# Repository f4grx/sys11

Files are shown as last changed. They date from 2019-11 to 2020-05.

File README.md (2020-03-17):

sys11
=====

This is a development board for the 68hc11 microcontroller.

The goal is to build a robust, simple, reliable, and repairable computer from
scrap, similar to what collapseOS is seeking.

The project defines two ROM images:
* a shell interface with assemble-time modular commands, development is halted.
* a forth interpreter.

Forth is a portable stack supported language wich is surprisingly powerful, even on
small targets. It has the potential to describe complex programs in a very compact way.

A lot of resources about forth are available online. This project defines a minimally small
forth interpreter with indirect threading. The goal is to build a 68hc11 interpreter that can
be used to write the interpreter itself, so it has to be as small as possible.

CPU: 68HC11A0, the most basic one. This is what I found in my drawer, and is
more desirable than a basic 6502 or other because it has integrated peripherals.
I only choose chips that I have replacement for.

Clock speed: 8 MHz XTAL / OSC, which translates to 2 MHz internal and
bus clock (Cycle time 500 ns). It seems that 16 MHz (4 MHz E clock, 250 ns
cycle) is also working. May switch to that later.

Currently sys11 is implemented on a protoboard using soldered 30AWG (wirewrap)
wires.

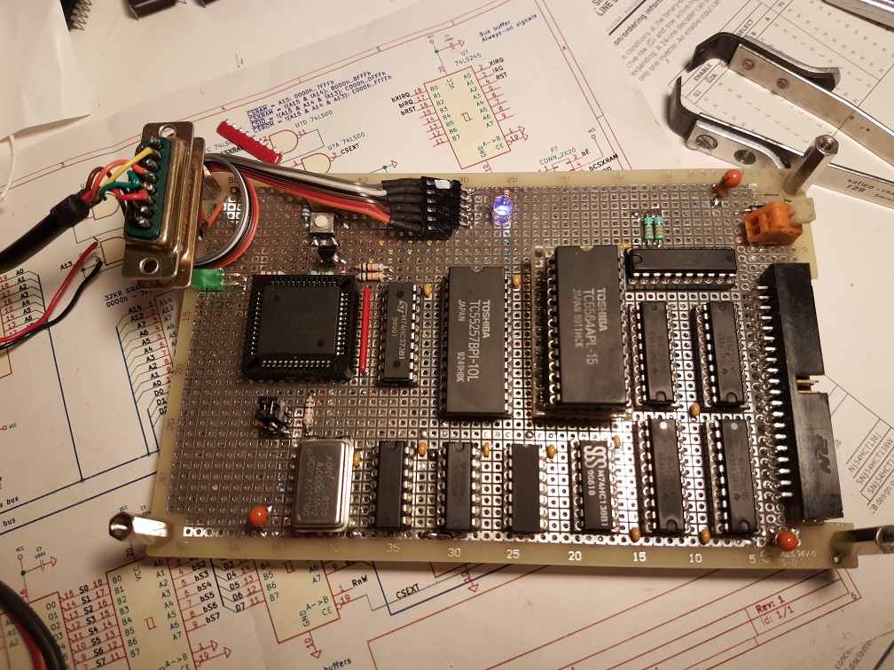
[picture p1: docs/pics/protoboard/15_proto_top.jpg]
Prototype top side


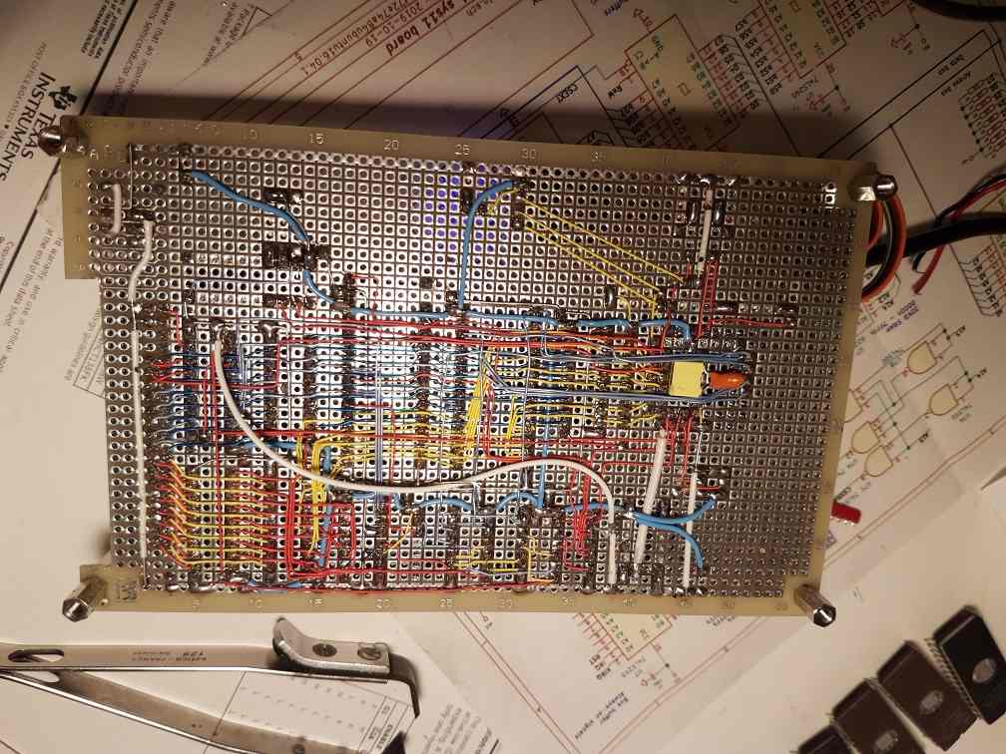
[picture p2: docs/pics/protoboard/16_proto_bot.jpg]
Prototype bottom side


Memory map (HC11 extended mode)
-------------------------------

* Internal RAM kept mapped at 0x0000
* Memory Mapped Registers mapped at 0x0000 (unusual). They overlay the internal
RAM, which means internal RAM locations 00h..3Fh are not usable (except the
locations that are reserved or related to PORTB and PORTC: 0002h-0007h).

* 32KB On-board Main SRAM (62256) in 0000h - 7FFFh CSRAM = A15
* 16KB Off-board secondary SRAM (half 62256) in 8000h - BFFFh, possibly banked
for additional space using a IO register. Then we could use an even bigger RAM
chip. CSXRAM = !(A15 & !A14)
* 8KB I/O space with 8 CS lines in C000h - DFFFh (1KB per CS)
CSIO = !(A15 & A14 & !A13)
* 8KB EPROM in E000h - FFFFh - monitor and SPI flash loader. For development,
this chip can be replaced with a RAM/EEPROM/NVRAM, the board actually use a
DIL32 socket instead of 28, that exposes the nWR line. An additional pair of DIL
sockets can be used to route this signal to the actual /WR line of the debug
RAM. This is actually using a 27256 EPROM with 4 manually selected banks, to
allow for different boot images (asm, communications, shell, storage mgmt, TBD)
CSROM = !(A15 & A14 & A13)
* External bus lines are only driven when external bus is actually addressed.
It is not driven when the on-board memory (32K RAM, 8K ROM) is addressed.
CSEXT = CSIO & CSXRAM

Main address decoding can be done with a few NAND gates (7400 2-input, and 7410
3-input NAND gates).

Peripherals
-----------

* 5V power from USB
* SCI : (UART), TX and RX lines on a pin header for external communication.
10K pullups are installed to ensure proper behaviour in bootstrap mode where
PORTD is configured as open drain.
* HE10-40 connector for external bus. All lines buffered by 74xx245.

Seriously planned features
--------------------------

* Robust 5V power supply (LF50 LDO, max voltage 40V) with reverse voltage
protection
* Additional LM2575 step-down to reduce LDO heating (bypassable).
* 3 outputs (PORTA) dedicated as SPI CS selector lines (3 bits + 74138 decoder +
normal /SS line)
* I2C bus using discrete N-MOS transistor on OC lines to drive the bus in open
* Multi-VPP EPROM programmer on a secondary board
* Fully shielded aluminum enclosure for a 100x160 board

Planned vaporware features
--------------------------

* Removable SPI/I2C flash cardriges
* SCSI
* Ethernet
* MCP2515 SPI CAN
* Additional UARTs and various comm interfaces (fiber, RS422 RS485...)
* Wireless communication interfaces (AX.25, 1200 bauds packet modem)
* Audio cassette program storage (Kansas)
* Dual-port RAM in IO space for communication and shared mem with another HC11.

What is already done
--------------------
* Memory map
* Schematic (includes errors)
* I have some chips: 4x 68HC11A0, 1x 68HC11A1, 1x 68HC11E2 (thanks vince),
some 74xx245, 573, 138, 00, 10, 27256, various 32Kx8 and 8Kx8 RAMs
* Ordered a 2864 EEPROM from ebay (received, meanwhile I found another one in a junkbox)
* Bootstrap uploader in Python3.
* Working hardware prototype on 100x160 perforated board
* Clock, Reset, UART connection, power supply with decoupling
* Memory map decoder using logic gates
* The HC11 starts in bootstrap mode and successfully executes code to drive LED.
* The HC11 is able to select the expanded mode and test the 32K RAM without
  errors (and also a RAM in the dedicated 8K EPROM space).
* bootstrap program to load more memory. Initally planned to use a custom HDLC
  protocol, but will rather load S-records directly.
* IRQ lines from expansion board to cpu (were broken due to lack of pullups)

Summary: The system is validated on the soldered wirewrap euro board.

What remains to be done
-----------------------
* Editing schematic to fix errors and match reality of prototype
* Finish simulating all opcodes
* Replace fifth LS245 registers with sth that allows open drain on RST and IRQs.
* Determine next step for hardware. Secondary board with more RAM? EPROM programmer?
* NVRAM SSD using these old bq4017 samples maxim generously offered me for free
  multiple years ago (Unfortunately this board will be a one-of-a-kind add-on
  unless you have these chips available or are able to find enough RAM chips)
* Some kind of documentation storage using big EEPROMs (27C040/27C080) mapped in IO
  space using a 256-byte window. This would allow use as block storage. Same idea
  applies to the bq4017 nvrams.
* I2C bus hardware
* Design a smaller PCB that can fit in a smaller shielded box.

Software roadmap
----------------
* Bootloader for extended mode - DONE
* Malloc - WIP, almost validated
* Simulator - WIP
* Basic shell - ABANDONED
* SPI bus driver - Should workd
* Block device system - ABANDONED
* Forth - WIP

* SPI and/or I2C EEPROM driver
* I2C bus driver

Abandoned features that should be implementable in forth
--------------------------------------------------------
* Assembler
* Self host the system

Abandoned features that are useless or too complex
--------------------------------------------------
Or may be done later...
* ed-based text editor
* Definition of a position independent binary format
* IO kernel
* Program loader
* RTOS

SPI bus
-------
The HC11 hardware SPI bus wil be used in master mode.
* The SS line is used as OE for a 74138 decoder that provides 8 CS lines from
3 OC lines of port A.

I2C bus
-------
A proper i2c bus needs two bidirectionnal open drain lines, which are not
available on the HC11 if one wants to benefit from the hardware SPI block on
PORTD. Moreover, the HC11 does not have a hardware i2c, so bitbanging must be
used.

The i2c bus will be done on port A using Input Capture and Output Compare lines.
To read SDA and SCL, the IC1 and IC2 lines are used. To write the bus, the OC1
and OC2 lines are used to drive small BS170 MOSFETs. This requires inversion of
the bits to write, which is not a big problem for the driver.

FAQ
---
Q: Why move to Forth?

A: At first I did not want it, and I planned to build an assembler and shell to
be able to compile source assembly files and rebuild the system from itself.
While doable, this will use a lot of memory, both flash and RAM. Just a shell and
still-not-working block device system was using 800 bytes, or 1/10 of the rom space.

It is pitiful to have 8k of ROM and only be able to have an assembler program, and
nothing else.

Meanwhile CollapseOS, which was going in the same direction, realized the potential
of forth and started implementing it. I followed the movement for several reasons:
* Forth is portable, the same routines are able to work on "any" forth implementing
machine, whatever the underlying CPU. This greatly increases the potential of collapse
recovery machines.
* It is still possible to write an assembler in forth, even cross assemblers are possible,
which still increases the ability to mix different machine in a portable software environment.
* It has the potential to express quite complex software constructs in a very compact manner

Q: Why not use a 6502?

A: Because the 6502 has a 8-bit stack pointer which is ridiculously restrictive.
We are not anymore in the situation where the 6800 was $179 and the 6502 was $29.

A2: Going to forth, the underlying CPU is not so important since Forth can be implemented
on a variety of machines.

Q: Why not use a Z80?

A: Because I did not have one when I started this project. However, I plan to
have an assembler for this target. If you want to play with the Z80, have a
look at the RC2014 project and/or github.com/hsoft/collapseos.

The HC11 is a microcontroller, which usefully comes with an integrated UART and
SPI peripherals. The Z80 does not, so it requires external bus peripherals.
However, the Z80 can hook these devices to its IO bus, saving space for more RAM
on the memory bus.

At some point it may be more interesting to build a Z80 system, to benefit from
more RAM, and also more registers, even if the Z80 requires more cycles to
execute every instruction.

Other CPUs are also interesting to increase the potential for collapse recovery:
ARM and MSP430 are such interesting targets, even the x86.

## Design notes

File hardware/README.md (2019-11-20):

sys11 hardware
===================

The most important part of this subproject is the schematic, that defines all
the components and their connection.

The circuit board can either be as a real two-sided PCB with SMD components for
compacity (the full SMD system can fit in a ebay 100x76x35 aluminium box).

But it can also be built on a pair of 100x160 prototyping boards, using a
HE10-40 and a ribbon cable, or a 64-pin Euro rack mount system. In that case,
connections can be either soldered or wirewrapped (!).

Design philosophy
-----------------
The secret goal of this project is to survive a technical apocalypse, even if
such an event is highly improbable and we would probably have more important
priorities than computers at that time.
Nevertheless, such a computer is interesting for educational purposes, and also
because it is likely much more robust and repairable than a modern computer.

BTW, if you want a more powerful computer, use an embedded ARM SoC (like stm32)
or a Raspberry Pi. However, if it breaks, dont ask me to fix it :p

Another goal of such a project is to allow programming of other computers
without having access to a more complex machine, so we will aim at developing
assemblers and uploaders for PIC, Arduino, and programmers for various memories
like EPROMS, EEPROMs, FLASHes, etc. that can be used in other designs.

Mini circuit board
------------------

The PCB and gerbers in this directory describe a board 100x70mm, that will fit
an ebay aluminium box of dimensions 100x76x35mm, using SMD components in SOIC
format. The resulting project is compact and somewhat repairable but requires a
lot of care not to burn the fine PCB traces. To help with repairs, each SMD
trace has two vias in it, which should reduce the risk of having lifted pads
when desoldering a SMD component. When desoldering a broken SMD component, it is
often desirable to limit PCB damage by cutting the chip leads with pliers, then
removing each of the still soldered leads one by one.

Connection between the two boards is achieved by a ribbon cable using straight pins
through the pcb, putting the ribbon cable in a u-shape. Board-to-board
stackable connectors can also be used.

Euro circuit board
------------------

This option is much larger but is much more robust than the mini circuit board.
All components can be removed and replaced, and connections can be reworked with
a lot of ease (just taking care not to burn the insulation of nearby wires).

Interconnections can use either soldered wirewrap 30AWG wire, or just plain
wirewrapping if sockets, tools and wires are available.

Connection between the two board is achieved by a ribbon wire on the side of the
boards, similar to what is used to connect IDE hard drives, except the full 40
pins are used, so the key usually found on IDE ribbon connector has to be
removed. The PCB is cut so that the socket and the plug of the ribbon do not
protrude outside of the euro board. This allows the user to build a simple and
robust metallic case from aluminum strips and flats.

Here is the current state of the prototype, top and bottom:

Prototype top side

Prototype bottom side

Enclosure
---------

Since one of the goal of this project is to bootstrap electronic circuits after
a civilization collapse, it is important to make sure that it can itself survive
the kind of difficult environment that may cause this collapse, including a
severe EMP event.

The only way to do that is to shield everything. So a proper metallic enclosure
has to be used. ebay has lot of extruded aluminium boxes suitable for both the
mini board and 100x160 boards. If the builder has machining resources, then it
is also possible to mill a box or build one from aluminium sheet and bars.

Connections are much more critical than the board itself. Since an EMP event
will induce high voltage in any wire that is not properly shielded, any
connector and opening in the project box is critical. I will only be using a
single SUB-D connector with the least amount of pins (probably 15). The
connector itself will receive a  metallic cover and will be disconnected when
the computer is not actively used.

Additional protections will be added on each electrical line crossing the box
through this SUBD connector: the possible components are gas discharge cells,
series resistors, and bidirectional transil diodes. The goal is to minimize the
impact of high voltages by reducing them to a low value if possible.

The ideal situation would be a single UART communication channel using
opto-isolated signals, like TOSLINK plastic optical fibers. Only the power supply would
then need severe EMP protections.

Prototype Progress
------------------
proto top 1
proto top 2
proto bot 3
proto top 4
proto top 5
proto bot 6

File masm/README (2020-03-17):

Motorola Freeware Assemblers for Unix (masm) [GFC]

Compiling: to build the 6811 assembler with the gcc compiler, simply run
gcc -o as11 as11.c
(you may get some warnings about malloc, those can be ignored)

For other assemblers, substitute the appropriate name for as11 in
the above gcc command.

I have used the 6805 and 6811 assemblers extensively and they work well.

This software is put together in a somewhat strange manner,
there's no Makefile and the main c programs are just a series of #includes.
But... it does produce a set of working assemblers.

This version has been built on SunOS, Solaris, and Linux.
Tested ok with Fedora Core 3 Linux on February 24, 2005.

Run the appropriate assembler with no arguments for a list of options.
example:

$./as11

Usage: ./as11 [file(s)] [- l b h s c d]

Version: March 17, 1996
    defaults to Motorola S19 file output
-h: Intel hex file output
-b: 64K binary image file output
-l: list file
-s: Symbol table dump
-c: cross reference output
-d: debug mode

To assemble a 6811 assembly file called test.asm do:
./as11 test.asm
 you should get the file test.s19 (S format hex file) as output.

Feed the S19 file to an eprom programmer or a 6811 loader such as the
BUFFALO monitor.

The original documenatation is below.
-----------------------------------------------------------------------

	      The IBM PC 6800/01/04/05/09/11 cross assemblers

GENERAL
	The assemblers are named as*.exe where '*' is  any
	of 0,1,h1,4,5,9 or 11 depending on which one you're using.  Command
	line arguments specify the filenames to assemble.

	The assemblers accept options from the command line to be
	included in the assembly.  These options are the following:

	    l	   enable output listing.
	    nol    disable output listing (default).
	    cre    generate cross reference table.
	    s	   generate a symbol table.
	    c	   enable cycle count.
	    noc    disable cycle count.

	The command line looks like this :

	       as* file1 file2 ... [ - option1 option2 ...]

	If this method of passing commands to the assembler is
	used rather than the OPT pseudo op code, a space should
	separate the minus sign from the last file name and the
	first option.  Example:

	   as5 program -l cre

	This command assembles file 'program' with an output
	listing and a cross reference table.

	The `S1' formatted object file is placed in file
	`filename.S19', the listing and error messages are
	written to  the standard output.  If multiple files are
	assembled, the 'S1' file will be placed under the first
	file's name.S19.

	The listing file contains the address and bytes assembled for each
	line of input followed by the original input line (unchanged, but
	moved over to the right some).	If an input line causes more than 6
	bytes to be output (e.g. a long FCC directive), additional bytes
	(up to 64) are listed on succeding lines with no address preceding
	them.

	Equates cause the value of the expression to replace the address
	field in the listing.

	Equates that have forward references cause Phasing Errors in Pass
	2.

	Expressions may consist of symbols, constants or the character	'*'
	(denoting the current value of the program counter) joined together
	by one of the operators: +-*/%&|^.  The operators are the same as
	in C:

		+	add
		-	subtract
		*	multiply
		/	divide
		%	remainder after division
		&	bitwise and
		|	bitwise or
		^	bitwise exclusive-or

	Expressions are evaluated left to right and there is no provision
	for parenthesized expressions.	Arithmetic is carried out in signed
	twos-complement integer precision (16 bits on the IBM PC)

	Constants are constructed with the same syntax as the Motorola MDOS
	assembler:

		'       followed by ASCII character
		$	followed by hexadecimal constant
		@	followed by octal constant
		%	followed by binary constant
		digit	decimal constant

ERRORS

	Error diagnostics are placed in the listing file just before the
	line containing the error.  Format of the error line is:

		Line_number: Description of error
			or
		Line_number: Warning --- Description of error

	Errors of the first type in pass one  cause  cancellation  of  pass
	two.  Warnings	do  not  cause	cancellation of pass two but should
	cause you to wonder where they came from.

	Error messages are meant to be self-explanatory.

	If more than one file is being assembled, the  file  name  precedes
	the error:

		File_name,Line_number: Description of error

	Finally, some errors are classed as fatal and  cause  an  immediate
	termination  of  the assembly.	Generally these errors occur when a
	temporary file cannot be created or is lost  during  the  assembly.
	Consult your local guru if this happens.

DIFFERENCES

	For indexed addressing, the comma is required before the  register;
	`inc x' and `inc ,x' are not the same.

		Macros are not supported.  (try M4 or M6)

	The force size operators ('>' and  '<')  are  implemented  for  all
	assemblers.

		The only pseudo-ops supported are:

			ORG, FCC, FDB, FCB, EQU, RMB, BSZ, ZMB, FILL
			PAGE and OPT.

		The OPT pseudo-op allows the following operands:

			nol	Turn off output listing
			l	Turn on output listing (default)
			noc	Disable cycle counts in listing (default)
			c	Enable cycle counts in listing (clear total cycles)
			contc	Re-enable cycle counts (don't clear total cycles)
			cre	Enable printing of a cross reference table
			s	generate a symbol table

		Some of the more common pseudo-ops are not present:

			SPC	Use blank lines instead
			END	The assembly ends when there is no more input
			TTL	use `pr' to get headings and page numbers
			NAM[E]	Did you ever use this one anyway?

		The above 4 pseudo-ops are recognized, but ignored.

	    ZMB (Zero Memory Bytes) is equivalent to BSZ (Block Store  Zeroes).
		FILL can be used to initialize memory to something other than zero:
		FILL val,nbytes.

TARGET MACHINE SPECIFICS

 (as0)	6800:	Use for 6802 and 6808 too.

 (as1)	6801:	You could use this one for  the  6800  and  avoid
		LSRD, ASLD, PULX, ABX, PSHX, MUL, SUBD, ADDD, LDD
		and STD.

 (as4)	6804:	The symbols 'a', 'x' and 'y'  are  predefined  as
		$FF, $80 and $81 respectively.	Also  defined  as
		'A',   'X'   and   'Y'.    Because  of  the  6804
		architecture, this means that 'clr x'  will  work
		since  the  x register is just a memory location.
		To  use  short-direct  addressing,   the   symbol
		involved  must	not  be a forward reference (i.e.
		undefined) and must be in the range $80-$83.

		Remember  that	bytes  assembled  in  the   range
		$10-$7F  will go into the data space; There is no
		program space ROM for these locations.

		The syntax for Register indirect addressing is as
		follows:
			  menmonic [<x>or<y>]
		an example is:
			    lda [x]
		the comma ',' is not allowed.

		The MVI instruction (move immediate) has its own
		format :

			 mvi address,#data   where address is
		   an 8-bit address in page zero, and data is
		   the value to be written to specified location.

 (as5)	6805:	There is no 'opt cmos' pseudo, so be careful  not
		to use STOP or WAIT in a program that is destined
		for  an  NMOS  version	of  the  6805.	 The  MUL
		instruction   should   also  be  avoided  on  all
		versions of the 6805 except the C4.  Cycle  times
		are for the NMOS versions.

 (as9)	6809:	The SETDP pseudo-op is not implemented.
		Use the '>' and '<` operators to force the size of
		operands.

			For compatibility, CPX is equal to CMPX.

 (as11) 68HC11: Bit manipulation operands are separated by  blanks  instead
		of commas since the 'HC11 has bit manipulation instructions
		that operate on indexed addresses.

DETAILS
	Symbol:  A string of  characters  with	a  non-initial	digit.	The
		string of characters may be from the set:

			   [a-z][A-Z]_.[0-9]$

		( . and _ count as non-digits ).  The `$' counts as a digit
		to   avoid   confusion	with  hexadecimal  constants.	All
		characters of a symbol	are  significant,  with  upper	and
		lower  case  characters being distinct.  The maximum number
		of characters in a symbol is currently set at 15.

		The symbol table has room for  at  least  2000	symbols  of
		length 8 characters or less.

	Label:	A symbol starting in the first column is a  label  and	may
		optionally  be	ended  with a ':'.  A label may appear on a
		line by itself and is then interpreted as:

			Label	EQU	*

	Mnemonic:  A symbol preceded by at least one whitespace  character.
		Upper  case characters in this field are converted to lower
		case before being checked as a legal mnemonic.	Thus `nop',
		`NOP' and even `NoP' are recognized as the same mnemonic.

		Note that register names that sometimes appear at  the	end
		of  a  mnemonic (e.g. nega or stu) must not be separated by
		any  whitespace  characters.   Thus  `clra'   means   clear
		accumulator A, but that `clr a' means clear memory location
		`a'.

	Operand:  Follows mnemonic, separated by at  least  one  whitespace
		character.   The   contents   of   the	 operand  field  is
		interpreted by each instruction.

	Whitespace: A blank or a tab

	Comment:  Any text after all operands for  a  given  mnemonic  have
		been  processed or, a line beginning with '*' up to the end
		of line or, an empty line.

	Continuations:	If a line ends with a backslash (\) then  the  next
		line  is  fetched  and	added to the end of the first line.
		This continues until a line is seen which doesn't end in  \
		or  until  MAXBUF characters have been collected (MAXBUF >=
		256 ).

FILES
	filename.S19	S-record output file
	STDOUT		listing and errors (use redirection for listing file)
	Fwd_refs	Temporary file for forward references.

IMPLEMENTATION NOTES
	This is a classic 2-pass assembler.  Pass 1 establishes the  symbol
	table and pass 2 generates the code.

							12/11/84 E.J.Rupp

	This version of the cross assemblers ported to the IBM PC 4/13/87

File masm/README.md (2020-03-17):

68hc11 absolute assembler found on http://www.solorb.com/linux8bit/

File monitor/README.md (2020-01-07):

Monitor
=======

The monitor has several roles. It mainly provides routines to be used by user
programs. It also manages the RAM and storage devices. It is really a very
little kernel.

Runtime environment
-------------------
Internal RAM AND Registers are both mapped at 0000h. Because of the access
priority enforced by the HC11, this means that both are available for
direct addressing, and there is no need to use X-relative addressing to compact
the code that uses register. X is then free for other uses.

* Addresses 00h .. 3Fh are the internal registers.
* Addresses 40h .. FFh are the internal RAM
* Addresses 0100h .. 7FFFh are the external RAM, managed by malloc
* Addresses 8000h .. BFFFh are the secondary RAM, usable as scratch data/code.
* Addresses C000h .. DFFFh are the Memory Mapped IO registers
* Addresses E000h .. FFFFh are the Monitor ROM.

Simulation
==========
gdb 8.3.1 still supports 68hc11 simulation. Program can be somewhat run using
the sim target but single stepping does not work. See the ../sim/README.md
document for how to use our custom simulator.

The gdb simulator currently has a bug that prevents me from remapping the I/O
registers via a write to INIT. It was reported to upstream with no feedback.

register relocation works on our custom simulator.

Application Binary Interface
============================

Overview and remarks
--------------------

It is important to ensure an homogenous function calling convention and binary
interface. This ABI should be easy to use in assembly and memory saving.

The HC11 has very few registers. Usually, X is used for index access to
peripheral registers mapped at 0x1000. We will avoid this by mapping registers
at 0x0000 (in the internal RAM) since it has several advantages:
* avoids having registers in the middle of the external RAM,
* allows to use the direct addressing mode
* free the X register for other uses.

Also the HC11 does not allow SP-relative addressing, so local vars and parameter
passing is not easy to achieve using the stack.

The ideal case would be to use X as stack pointer. However this use wont be
systematic.

Soft registers
--------------
The HC11 definitely does not have enough registers for comfortable programming.
We will increase the number of available registers by statically allocating some
internal RAM addresses as static registers. For the moment 8 16-bit soft regs
are allocated, sp0 to sp3 and st0 to st3. They are allocated in page0 to allow
access using the direct address mode, avoiding the extended mode.

Caling functions
----------------
* Parameters in soft registers sp0..sp3
* Local vars in st0..st3
* X,A/B/D,Y can be used for computations (Only A/B/D allows full arithmetics).
* If any reg has to be preserved across a call, it has to be saved on the stack.
* Return value in D

Shell
=====
The shell reads commands on the HC11 SCI, and then recognizes and execute them.

For the moment there is an echo command that can be used to switch local echo
on/off.

File System and File Storage
============================
A full uniform VFS like in Unix requires a root device or a RAMFS to define the
mount points. To save this, storage devices are mounted as volumes, like DOS.
However, unix-style paths are used to refer to files within volumes.

The following rules apply
* Absolute paths start with a /
* Relative paths start with something else
* The root directory / can not hold files, only mount points.
* It is possible to use ls on the root dir, this is used to enumerate active
mount points
* The mount points have single character numeric ASCII identifiers that map
directly to the volume ID.

VFS state includes the following variables:
* Current volume ID
* Current path inside current volume (max 40 chars). Root dir is an empty
string.

Some filesystems do not support nested directories. In that case all files are
directly stored in the root directory of the volume.

Block devices
-------------
Block devices are registered at boot. They are identified by an integer.
Devices are stored as a table of N pointers to a set of functions pointers:

* OpenDevice - Mark an open flag to ensure exclusive access
* CloseDevice - Release flag
* CountBlocks - Returns number of blocks
* ReadBlock - Does what it says
* WriteBlock - Does what it says

There is a ```block``` command that can list registered devices and dump them.

FS types
--------
The only FS type used at the moment is a simplified version of RRSF, with
identifier 0.
Filesystems are stored as a table of N pointers to a set of function pointers:
* OpenFile
* CloseFile
* Seek
* Read
* Write
* OpenDir
* GetNextDirEntry
* DeleteCurEntry
* RenameCurEntry
* CloseDir

Volumes
-------
Volumes can be registered dynamically using the mount command to bind together a
block device and a filesystem type with some state.

Volumes are stored in a table that holds the following info:
* Pointer to block device functions
* Pointer to FS functions
* TODO storage for volume state (cur dir, etc)

There is a set of commands to interacting with files in mounted volumes.
* mount,umount
* cd,ls,cat,mv,rm

assembler
=========
The assembler is critical to sys11 self hosting. It requires storage for the
source and binary files, but its main binary is stored in the monitor ROM.

Position independent executable format
======================================
sys11 can load executables from storage, load them in RAM and execute them.
In such a system, it is not possible for these programs to assume anything about
the address at which they are loaded, or about the address at which program
variables must be stored.

Relocations
-----------
Such a program is linked at address zero. A zone of the program registers every
offset in the program that holds an actual jump address.
Relocation is a process that runs before starting the program, where each
registered jump address is fixed by adding the start address of the program.

Data relocation does not happen this way. For future plans where a RTOS will be
implemented, we need to support parallel execution of multiple copies of the
same program. Because of this, the data start address is stored in the X
register, and all accesses to global variables of the program must happen
relative to X.

Disk Format of executables
--------------------------
On the disk, a program has this fields, in order:
* a 16-bit magic value TBD
* a 16-bit size of the text/rodata section
* a 16-bit size of the bss section
* (There is no support for initialized data yet)
* a 16-bit relocation count
* For each relocation, 16-bit offset to be patched in the program
* N-bytes of program data

System calls made available to the user
=======================================
User programs can call the ROM using software IRQs.

Parameters are set in sp0..sp3, function is stored in A, and SWI is executed.

A  | Function  | Params                     | Retval in D
---+-----------+----------------------------+----------------
00 | open      | Pointer to path, mode      | File descriptor
01 | close     | File descriptor            | Status
02 | read      | File Descriptor, Dest, len | Status
03 | write     | File Descriptor, Src, len  | Status
04 | mount     | DevID, Path                | Status
05 | malloc    | Size                       | Pointer
06 | realloc   | Pointer, Size              | Pointer
07 | mfree     | Pointer                    | void
08 | run       | Pointer to path            | Return code
09 | exit      | code                       | (noreturn)
0A | sleep     | milliseconds               | void

Built in peripherals
--------------------
*SPI
*I2C

malloc/free
===========
The 32K RAM in 0100..7FFFh is managed as a heap.

An additional 8K may be available at 8000..9FFFh (total 40k).

External memory at A000h..BFFFh can be a ROM extension or even more RAM
(total 48k).

Actually a few bytes are used in this RAM for the kernel. For the moment this
includes the current command line for the shell.

Algorithm
---------

The heap is managed as a linked list of free blocks. a separate 16-bit variable
is required to hold the head of the free list. This can be the first two bytes
of the heap itself, or some 16-bit variable in page0.
Each block (allocated or free) has a 2-byte header indicating the size of this
block. Each free block has also a pointer to the next free block.
The linked list of free blocks is kept ordered by increasing address.

Initialization: Define a single large free block.

Allocation: Traverse the list of free blocks. If free block is big enough,
* split block by creating a new free block after the bytes that will be reserved
* Return pointer to block

Deallocation: Find prev,next pointers at offset -2 from beginning of block.
* Insert this block in the free list
* Coalesce the list of blocks, starting from the head, restarting if anything
happens.

Reallocation: (TODO)
* Find the free block that follows the allocated block
* If contiguous and big enough, grow the block into this free space, fix sizes
and pointers, done
* If not contiguous or not big enough: Attempt to find a new block, then free
the old one.

RTOS:
* Add a task ID field in the header so all allocations of a killed task can be
freed automatically

exec
----
* If program already loaded, increment refcount of program, else
* Allocate RAM for code/rodata segment
* Load program segment from filesystem to program RAM
* Read and apply relocations
* After program is loaded/found:
* Allocate RAM for bss/stack segment
* Zeroize bss segment
* Put address of global var segment in known place
* Start executing program segment (RTOS: create task)
* After execution, free data segment
* Decrement refcount of program
* If refcount is zero, free code segment

For the moment this is a simple execution but in the future we will support
multiple tasks with code segment sharing.

kernel init
-----------
* Register sci as char device 0
* Open device 0 as FD 0: can be used for text input/output
* Try to mount a FS in I2C or SPI bus
* If that fails, start an internal emergency shell
* Try to exec the shell process in file /shell

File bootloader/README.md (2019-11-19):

stage2.asm Bootloader
=====================

This program is a second stage bootloader to test programs without having an
EPROM programmer.

In bootstrap mode, the 68HC11 will load 256 bytes from the SCI into the internal
RAM at address zero, and then run it.

We use this feature to allow loading a full s-record file in the memory map.

The EPROM socket has 32 pins even if a 27256 is 28-pin. This header has the
~WR signal on it. This allows the use of a special small PCB header to use a
62256 in place of the normal 27256 (basically, switch around the A14, VPP, and
~WR lines).

With this setup, it is possible to load some code in the D000h.FFFFh range and
run it as if the system had real EPROM. This can be used to develop the first
programs that you will run on this board.

Of course this means that the program is volatile, unless you use some
battery-backed RAM from Dallas or a 2864 EEPROM.

Loading algorithm:
------------------

* We Reuse UART settings installed by the bootstrap ROM
* Init extended mode by clearing HPRIO.MODA
* Wait for a S character
* Read all chars until LF or overflow
* Read type char (0-9)
* Read Length and address hex pairs
* If this is a S1 line, convert hex pairs, write to mem
* If this is a S9 line, jump to address
* Else signal an error

This is pretty much all that can be done safely in 256 bytes of RAM.

Note that there is still room for optimization in this code, that was
written very naively.

Build process
-------------
The only requirement is binutils compiled for 68hc11 and make

The Makefile is common and uses some make iterations and magic to generate
build targets.

Other programs
--------------
This directory also contains some small test programs that can run directly
from the bootstrap rom:
* a memory dumper
* a copy of this, made to read the internal EEPROM of a HC11E2
* a RAM tester to ensure the external bus is wired properly

These programs can be uploaded in a HC11 in bootstrap mode using upload.py from
the tools directory.

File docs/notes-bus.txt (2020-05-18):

IOconn
 1 | SPICS1
 2 | SPICS2
 3 | SPICS3
 4 | SPICS4
 5 | SPICS5
 6 | SPICS6
 7 | SPICS7
 8 | SPICS8
 9 | GND
10 | VCC
11 | MISO
12 | MOSI
13 | SCLK
14 | SDA
15 | SCL
16 | TXD
17 | RXD
18 | nIRQ
19 | 
20 | 

BusConn
 1 | AD0
 2 | AD1
 3 | AD2
 4 | AD3
 5 | AD4
 6 | AD5
 7 | AD6
 8 | AD7
 9 | A8
10 | A9
11 | A10
12 | A11
13 | A12
14 | A13
15 | A14
16 | A15
17 | GND
18 | E
19 | GND
20 | RW
21 | nIRQ
22 | nXIRQ
23 | +5V
24 | nRST
25 | AS

DIN 41612 rack based on STEbus
GND       |a 1 c|  GND
5V        |  2  |  5V
D0        |  3  |  D1
D2        |  4  |  D3
D4        |  5  |  D5
D6        |  6  |  D7
A0        |  7  |  GND
A2        |  8  |  A1
A4        |  9  |  A3
A6        |  10 |  A5
A8        |  11 |  A7
A10       |  12 |  A9
A12       |  13 |  A11
A14       |  14 |  A13
--        |  15 |  A15
--        |  16 |  --
(CM0) R/nW|  17 |  --
(CM2) 5V  |  18 |  (CM1) 5V-mem (0V-IO)
--        |  19 |  GND
          |  20 |  E
--        |  21 |  GND
IRQ       |  22 |  nRST
--        |  23 |  XIRQ
--        |  24 |  --
--        |  25 |  --
GND       |  26 |  --
          |  27 |
          |  28 |
16MHz     |  29 |  
(-12V)    |  30 |  (12V)
5V        |  31 |  5V
GND       |  32 |  GND

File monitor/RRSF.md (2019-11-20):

RRSF13 System of Files
======================

Overview
--------
The ROT13 of RRSF is EEFS, which stands for EEPROM File System, but the EEFS
acronym is already used for an unrelated EEPROM filesystem made by NASA.

RRSF also means Recycled Rubber Steel Fiber, RACF Remote Sharing Facility, Reeva
Rebecca Steenkamp Foundation, Recruitment And Retention Shared Facility, or
Reseau Rail Sans Frontieres, all of which have absolutely nothing to do with a
file system.

This filesystem is intented for use on serial EEPROM devices. Some efforts are
made to ensure some wear leveling, but it is still easy to abuse the device.
More efforts have been made to ensure that operations are still safe if the
power is lost with no previous notice.

Intended Physical devices
-------------------------
Largest I2C/SPI EEPROM is (2 Mbit, 256k x 8-bit)
Atmel/Microchip AT25M02 / AT24CM02 (1M Write cycles, 100 years retention)
ST M95M02 / M24M02 (4M Write cycles, 200 years retention)
That means 262144 bytes in 1024 256-byte pages
byte address need 18 bits for encoding.
page addresses need 10 bits for encoding.
These I2C EEPROMS have an external address line, so two of them can be used on
the same bus for a total of 512kbytes, in a kind of RAID0 fashion.

This filesystem can also be used in good old RAM/EEPROM/EPROM, speficically with
a banked memory system that allows a 256-byte view on the page, with the rest of
address bits kept in separate latches. With the current FS encoding, it is
possible to support 65536 pages of 256 bytes, for a total of 16777216 bytes.
That would be 16 Mbytes or 128 Mbits.

In the future we will extend the FS with 32-bit page pointers which will allow
for much more room.

Min Write unit in these serial chips is 4 byte (one word) (for ECC protection).
Max Write unit is 256 bytes (one page).

Reads can be of any arbitrary size, but it is a good idea to stick to one-page
reads only.

FS parameters
-------------
The only parameter is FILENAME_MAXSIZE, which is 16 bytes. This also apply to
directory names.

A FS journal could be added in the future:
1) Write transaction to journal, 
2) Write a validation flag, 
3) Do the transaction on the actual FS,
4) invalidate journal entry.

This would have a penalty on the wear leveling if the number of journal blocks
is too small.

Device organization
-------------------
Storage is organized in 256-byte pages
Each page has a 4-byte header with a type that describes its function
```
Offset | Description
-------+------------
00h    | Page type
01h    | For pages with type=1, Number of valid bytes in the page. Else, FFh.
02h    | Index of next page (FFFFh if none)
```

```
Type   | Description
-------+------------
00h    | Superblock
01h    | File data
02h    | Directory
03h    | Symbolic Link
04h    | Garbage list
FFh    | free
```

File metadata
-------------
Files and dir have simplified metadata. They have an owner ID on one byte, and
separate read/write/execute bits for the owner and other users. There is no
notion of group.

Page allocation
---------------
When mounted, storage is scanned and the last used page is noted.
Page allocation is then strictly sequential and starts after the last used page.
When the last page of the device is reached, the sequence restarts at the first
page.

Sequential allocation is the only mechanism that attempt to minimize eeprom
wear. Defragmentation is not used since all pages can be reached with the same
delay.

A page is considered used when the first byte of the page is not FFh. This means
that releasing a page just requires writing FFh in its first word.

When it is not possible to allocate a page in a device, garbage collection (see
below) is attempted before declaring failure.

File data pages
---------------
File data is stored in pages with type=01h.

Since the file size is not stored in directory entries, getting the size of a
file requires browsing all the pages of the file.

The first bytes of the first page of a file are not user data but file metadata.
```
Offset | Size             | Description
-------+------------------+------------
00h    | 01h              | Access rights (0-0-OX-OW-OR-X-W-R)
01h    | 01h              | Owner ID
02h    | 02h              | Page index of the parent directory (for file erase
       |                  | recovery)
04h    | FILENAME_MAXSIZE | File name
```

As a consequence, the first page holds 232 bytes of user data, and the next
pages hold 252.

Directory pages
---------------
Directory pages have type=02h and the same structure of file pages, except that
file data is replaced by page indexes to child files and directories. Parent
directory is stored the same way as files.

Symbolic links
--------------
Links are similar to files but have type=03h and the file contents is the path
to the target file. Hard link are not supported to avoid reference counting of
data pages.

Garbage pages
-------------
Garbage pages are a doubly linked list of pages that are no longer in use by the
filesystem, and that must be freed at the next occasion. They are indicated with
a type=04h. The other bytes in the first word are not changed, since they will
indicate a valid next page that must also be erased.
The use of this list is to make sure that unused pages are really freed, since
it requires less operations to link deleted pages to garbage than to free them
effectively.

The superblock contains the index of the next garbage page, of FFFFh if there is
no garbage page.

The index of the last page added to the garbage chain is kept in RAM. It is used
when directories are deleted and files are deleted or truncated, to easily add
new pages at the end of the garbage list.

When some pages of a file/dir are not used, the first page of the chain to
delete is appended to the list of garbage pages:
1) set the page type to 04h (this is atomic)
2) set the NEXT pointer of the last garbaged page to the index of the new page
   chain to be deleted
3) Remember the new index of the last page of the resulting chain.

If nothing more is done at this point, a file/dir can point to garbaged pages.
At the time of mounting, when the directories are traversed, if any dir/file has
a page that is garbage, the file/dir is truncated by setting the next pointer of
the last non-garbage page to FFFFh.

Superblock
----------
The superblock contains meta data about the filesystem.

```
Offset | Description
-------+------------
00h    | Type 00h
01h    | FS options: 01h: read only, others bits RFU
02-03h | RFU
04-05h | Pointer to root directory
06-07h | RFU
08-0Fh | Volume label
10-13h | Format flag, 00h: being formatted, FFh: format complete
14-15h | garbage head (FFFFh if none)
16-FFh | RFU
```

Formatting
----------
1) Set flag in superblock as "being formatted"
2) Mark all used blocks in the device as free (just write the header)
3) Create a root directory
4) Write a superblock with a reference to the root dir
5) Set flag in superblock as "not being formatted"

Mounting
--------
1) If superblock indicates "being formatted", do a format then reset this flag
2) Traverse the directories depth first (can be done without a stack, just with
   current/parent dir pointers):
   1) if any child entry in a directory points to a page that is in
        the garbage list (type=04h), set the directory entry to FFFFh.
   2) When all entries in a directory have been traversed, cleanup this
        directory (see below).
   3) When browsing the next page of a directory or file, if that page is in
        the garbage list (type=04h), then set the "next" pointer of the current
        page to FFFFh (truncation).
3) Cleanup the garbage chain: Browse it forward to define the previous links
(stored in the first bytes after the header of each page), then browse it
backwards to free the garbage pages, starting from the last one. This requires
writing a single FFFFFFFFh word in the page header. Note: We release pages from
the last one to avoid breaking up the garbage list. If power is cut at any
moment in this process, we can just restart the cleanup at next mount.

Optional: Full garbage collection by determination of reachable pages.
Since the largest serial EEPROM device has 1024 pages, allocating one bit for
each page requires just 128 bytes per device. The maximum volume size of 65536
pages would require 8k, which is more critical but still doable. A directory
traversal can be used to determine the extensive list of reachable pages,
and set free all the unreachable pages that dont have a type set to FFh.

Directory creation
------------------
1) Allocate a named page with type 02h and no "next" pointer, having the current
   directory as parent
2) Populate dir rights, owner and name
3) Create a new child entry in the current dir
TODO analyze partial execution and recovery options

File creation
-------------
1) Allocate a page with type 01h and no "next" pointer, having the current
   directory as parent
2) Populate file rights,owner and name
3) Create a new child entry in the current dir
TODO analyze partial execution and recovery options

Child creation in current dir
-----------------------------
This is used to add a file or dir to the current directory
1) Find a FFFFh entry in the current dir (that may be between two existing
   entries, or at the end of the list of entries). The directory may span on
   multiple pages, child entries do not have to be stored by name.
2) If no entry is found,
   1) Create a new directory page. If page not erased, do a full page erase.
   2) Link this page as next page of the current directory
   3) This page will obviously have entries, so retry the first step
3) Set the entry to the index of the first page of the child
TODO analyze partial execution and recovery options

Directory deletion
------------------
Only empty directories can be deleted. This means only one page has to be freed.
The current directory has to be the parent directory of the entry being deleted.
1) If directory to delete is not empty, fail.
2) Add the directory page to the garbage list.
If power is cut here the next mount operation will find the deleted dir and
clean it up.
3) Set the entry to this directory to FFFFh
If cleanup is not done bc of power cut, it will be reattempted at next mount
4) Cleanup the directory
TODO finalize analyze partial execution and recovery options

File deletion
-------------
1) Add the first page of the file to the garbage list
If power is cut here the next mount operation will find the deleted dir and
clean it up>
2) Set the directory entry to this file to FFFFh
If cleanup is not done bc of power cut, it will be reattempted at next mount>
3) Cleanup the directory
TODO finalize analyze partial execution and recovery options

Directory cleanup
-----------------
This process has to happen after a directory or file is deleted.
1) While there are holes in the list (FFFFh entries), swap this entry and the
   last entry of the directory. This ensures that the list has no holes.
2) If this process results in removing the last entry of the last directory
   page, then add the last page of the directory to the garbage list and fix the
   next pointer of the previous page.
TODO analyze partial execution and recovery options
   
File data writing
-----------------
The current size of a file is determined at file opening by counting full pages
and adding the number of valid bytes indicated in the header of the last page.
Obviously, if bytes are written one by one, the page header (and to a lesser
extent the file page bytes themselves) will wear much faster than other bytes.
A RAM buffering mechanism can be used to reduce the number of writes in the
header, at the expense of data loss if power is cut, but this is not mandatory
per filesystem design.
Incoming data bytes are just written to the proper offset in the existing file
pages.

If file pointer is at the end of the file, this is an append, not a write.

File appending (growing)
------------------------
When the write pointer is at EOF, two situations happen:

Write beyond the file size within the same page:
1) Write the byte at correct offset
2) Update the page use size in the page header
If the data does not fit in the last page of the file, a new file page must be
allocated:
1) Allocate a page with type 01h and no "next" pointer
2) Write the data and length in header if the page will not be used in full
3) Update the header of the previous page to point to this new next page
4) Repeat this until all data has been appended.
TODO analyze partial execution and recovery options

File truncation (shrinking)
---------------------------
This is equivalent to a partial file deletion.
1) Find the page that contains the truncation point
2) Update the valid number of bytes in the header
3) Add the page that follows the truncation point to the garbage list
4) Fix the next pointer of the current page
TODO analyze partial execution and recovery options

EOF

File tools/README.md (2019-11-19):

Installing toolchain
====================

The last version of GNU binutils still supports 68hc11

```
# wget https://ftpmirror.gnu.org/binutils/binutils-2.33.1.tar.xz
# tar Jzvf binutils-2.33.1.tar.xz
# cd binutils-2.33.1
# ./configure --prefix=... --target=m68hc11-elf
# make -j
```

upload.py
=========

This tool can be used to upload a program to a 68HC11 in bootstrap mode. The
binary to upload must be 256 bytes exactly. The provided makefile ensures this.

Note that if your bootstrap program reinitializes the uart too fast, the upload
tool will not receive acknowledgement for the last uploaded byte. The programs
in the bootloader directory have code to wait for the Transmit Complete event
managed by the SCI.

The bootloader/ directory contains a bootstrap program that can be used to
upload more elaborate programs, including writing to external RAM/EEPROM/Flash
memories. To use it, you have to link or copy the stage2.bin program into the
tools directory.

```
usage: ./upload.py [-h] [--port PORT] [--xtal XTAL] [--fast]
                   [--reset {no,rts}] [--srec SREC] [--term]
                   [binary]

positional arguments:
  binary            binary to upload, mandatory unless using stage2 (256
                    bytes)

optional arguments:
  -h, --help        show this help message and exit
  --port PORT       serial port to use (default /dev/ttyUSB0)
  --xtal XTAL       HC11 XTAL frequency in MHz (default 8)
  --fast            Use the fast /16 baud rate instead of usual /104
  --reset {no,rts}  reset before upload (default no)
  --srec SREC       program to upload using stage2-srec after bootstrap is
                    done
  --term            Keep running in terminal mode after upload
```

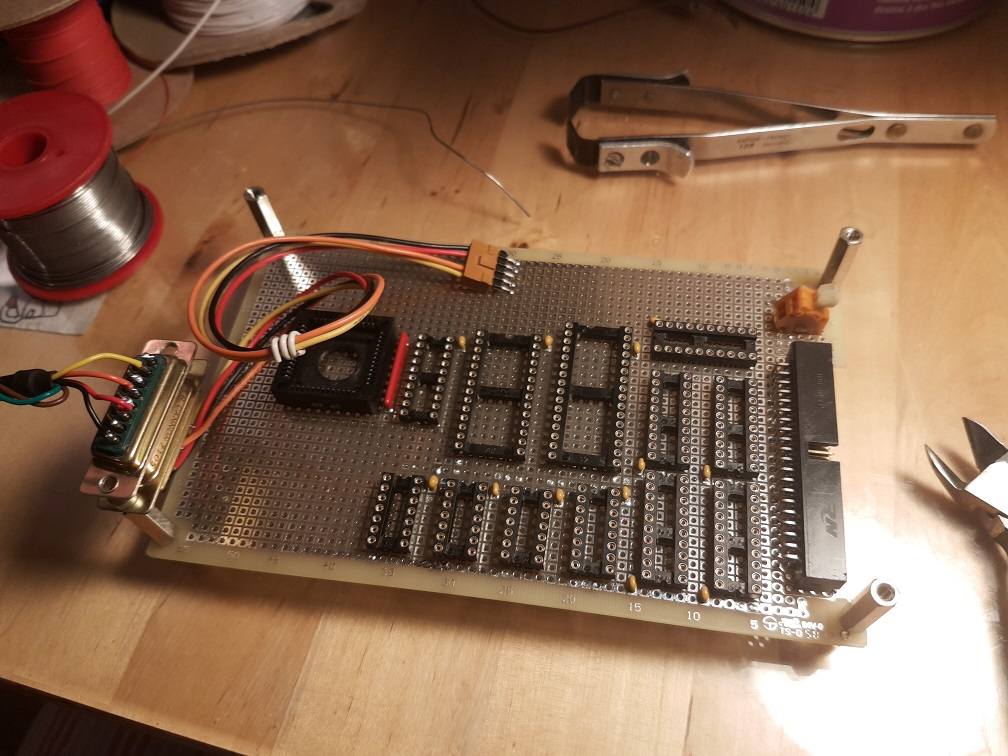
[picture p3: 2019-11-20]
docs/pics/protoboard/05_proto_top.jpg

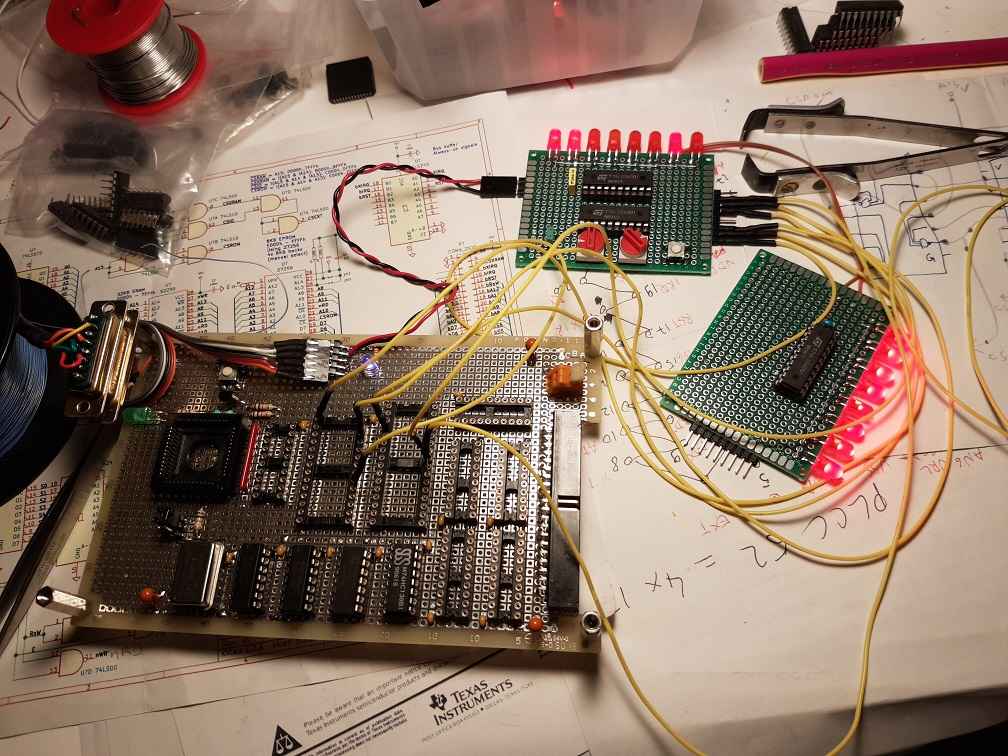
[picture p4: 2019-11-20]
docs/pics/protoboard/13_proto_top.jpg

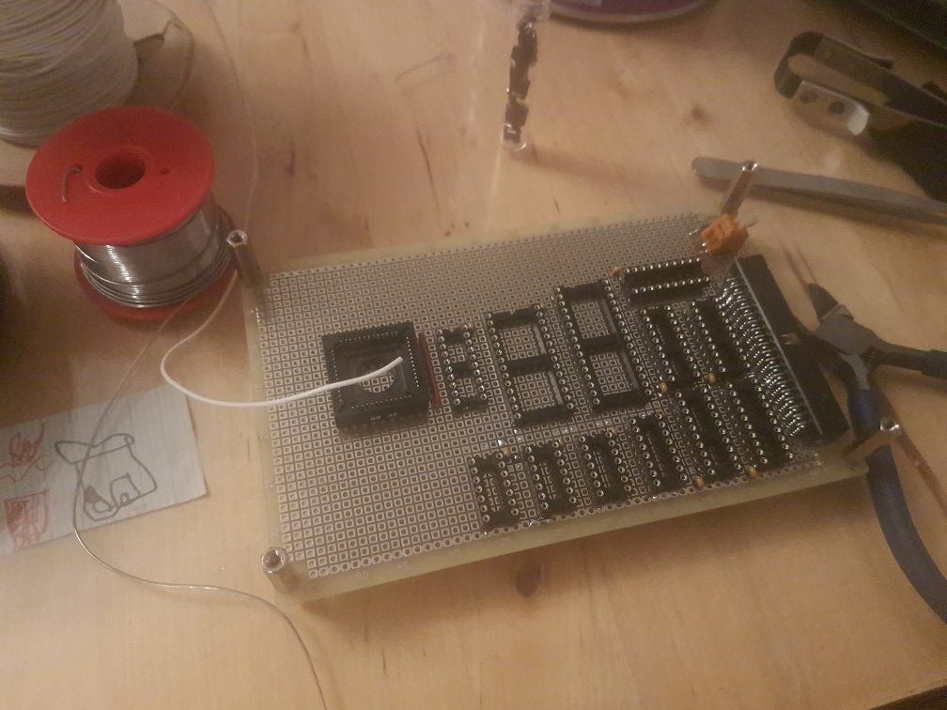
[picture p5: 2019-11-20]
docs/pics/protoboard/04_proto_top.jpg

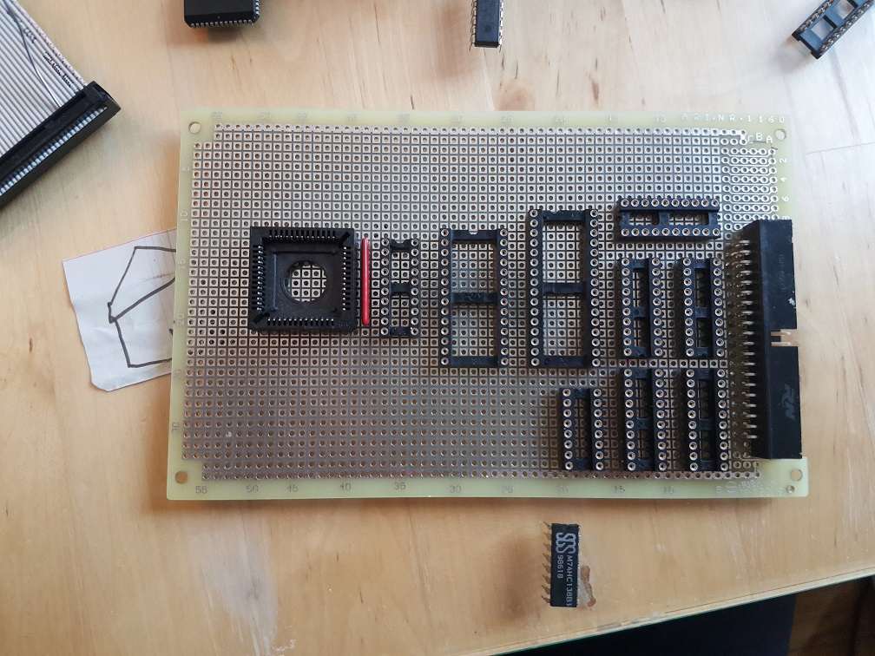
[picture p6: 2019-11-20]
docs/pics/protoboard/02_proto_top.jpg

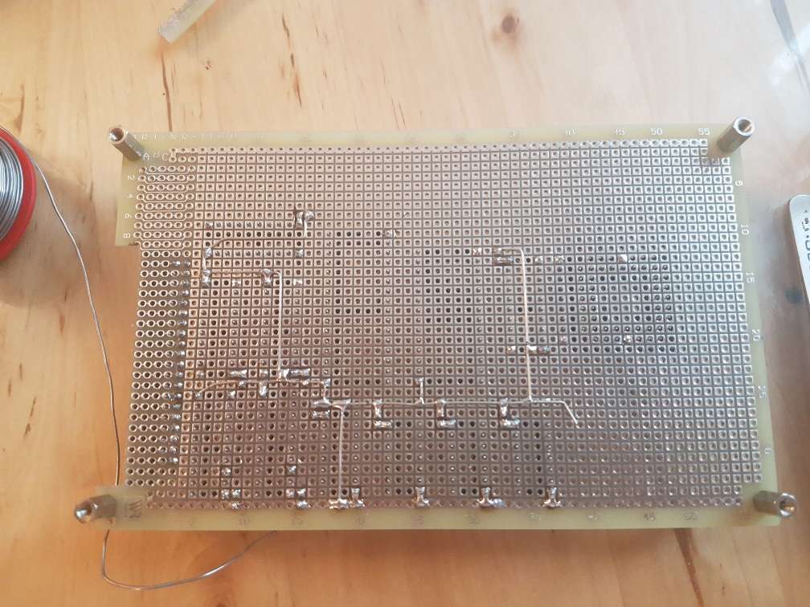
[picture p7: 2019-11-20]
docs/pics/protoboard/03_proto_bot.jpg

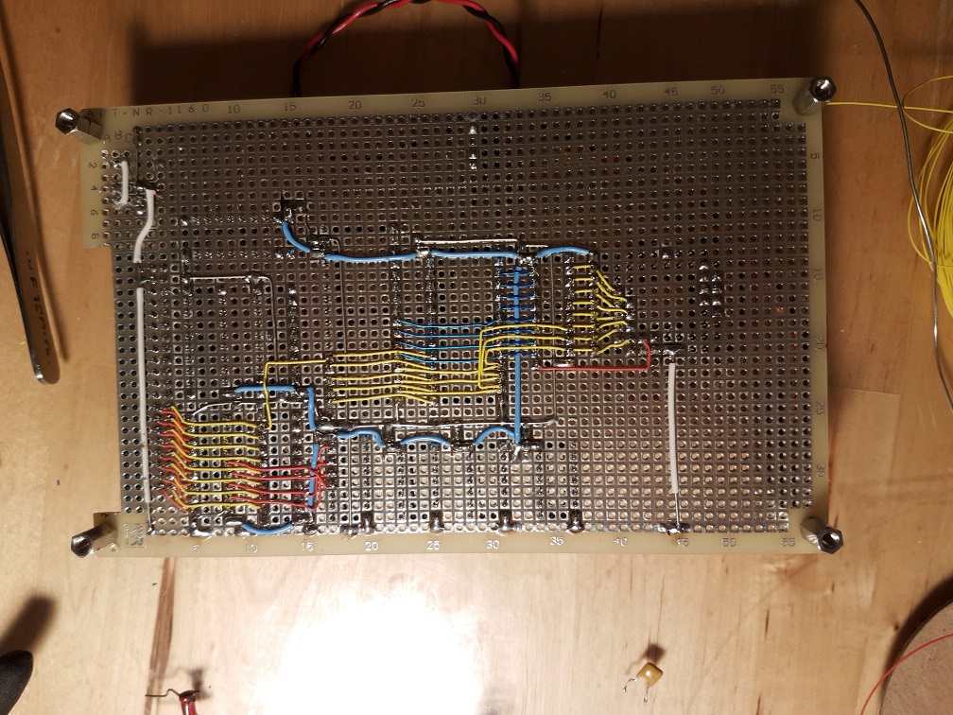
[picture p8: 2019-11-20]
docs/pics/protoboard/08_proto_bot.jpg

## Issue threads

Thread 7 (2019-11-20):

gdb HC11 simulator does not want to remap IO registers

f4grx, 2019-11-20:
```
Starting program: /home/grx/sys/bin/m68hc11-elf-run monitor.elf

Breakpoint 4, m68hc11cpu_io_write (val=0 '\000', addr=61, cpu=0x711590, me=0x715200) at dv-m68hc11.c:1022
1022		uint8 old_bank = cpu->ios[M6811_INIT];
(gdb) n
1024		cpu->ios[M6811_INIT] = val;
(gdb) n
1028		if ((old_bank & 0x0F) != (val & 0x0F))
(gdb) n
1030	            struct m68hc11cpu *controller = hw_data (me);
(gdb) n
1032	            hw_detach_address (hw_parent (me), M6811_IO_LEVEL,
(gdb) n
1030	            struct m68hc11cpu *controller = hw_data (me);
(gdb) n
1032	            hw_detach_address (hw_parent (me), M6811_IO_LEVEL,
(gdb) n
/m68hc11: hw_attach_address: no parent attach method
sim_resume (sd=sd@entry=0x711010, step=step@entry=0, siggnal=0) at ./../common/sim-resume.c:61
61	  if (jmpval == sim_engine_start_jmpval
(gdb) bt
#0  sim_resume (sd=sd@entry=0x711010, step=step@entry=0, siggnal=0) at ./../common/sim-resume.c:61
#1  0x0000000000403539 in main (argc=<optimized out>, argv=<optimized out>) at ./../common/nrun.c:187
(gdb) q

```
no parent attach method

This prevents me from simulating the monitor.

currently rebuilding with -O0 to get a better debug experience in host gdb...

f4grx, 2019-11-21:
Reported to GDB maintainers as:

https://sourceware.org/bugzilla/show_bug.cgi?id=25211

The patch posted here fixes the problem.

f4grx, 2022-02-08:
still not fixed upstream as of jan 2022

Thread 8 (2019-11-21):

Not using a 6502 is a big flaw

Godzil, 2019-11-21:
Just because :open_mouth:

We are in 2019 and 256 byte of stack is enough for everyone!
And nobody need C, so that stack issue is a non one!

f4grx, 2019-11-21:
Okay! Next-next board maybe (I have some chips)
Next one will be Z80.

Closed 2019-11-21.

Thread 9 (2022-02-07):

Schematic: add pullups on IRQ lines

f4grx, 2022-02-07:
during debugging monitor code, IRQ lines got floating low, which resulted in a permanent IRQ when using RTI with interrupts unmasked to execute user code.
normally U14 forces the lines high, but if not connected, irq lines are floating ->bad

f4grx, 2022-02-08:
pullup installed on prototype board. verified that monitor can execute code again even with irqs enabled.

next board should use N-mos for open drain on irq lines, not  push pull drivers, so compare output can be used on xirq for instruction tracing function without interfering with external xirq sources.

=> remove U14, replace with a bunch of BS170

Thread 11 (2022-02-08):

reduce IO space

f4grx, 2022-02-08:
on the initial revision, IO was chosen as 8 KB in C000-DFFF
this is very large

rework IO to a smaller size and use the reclaimed space for XRAM
256 or 1024 bytes should be enough for IO

solution: for example use 23K RAM on 8000-DBFF and 1K (400h) IO in DC00-DFFF (priority over ram)

IO connector: use 8+2 address bits for 4x 256 bytes spaces and 4 cs lines (1k IO, 256 bytes each CS)

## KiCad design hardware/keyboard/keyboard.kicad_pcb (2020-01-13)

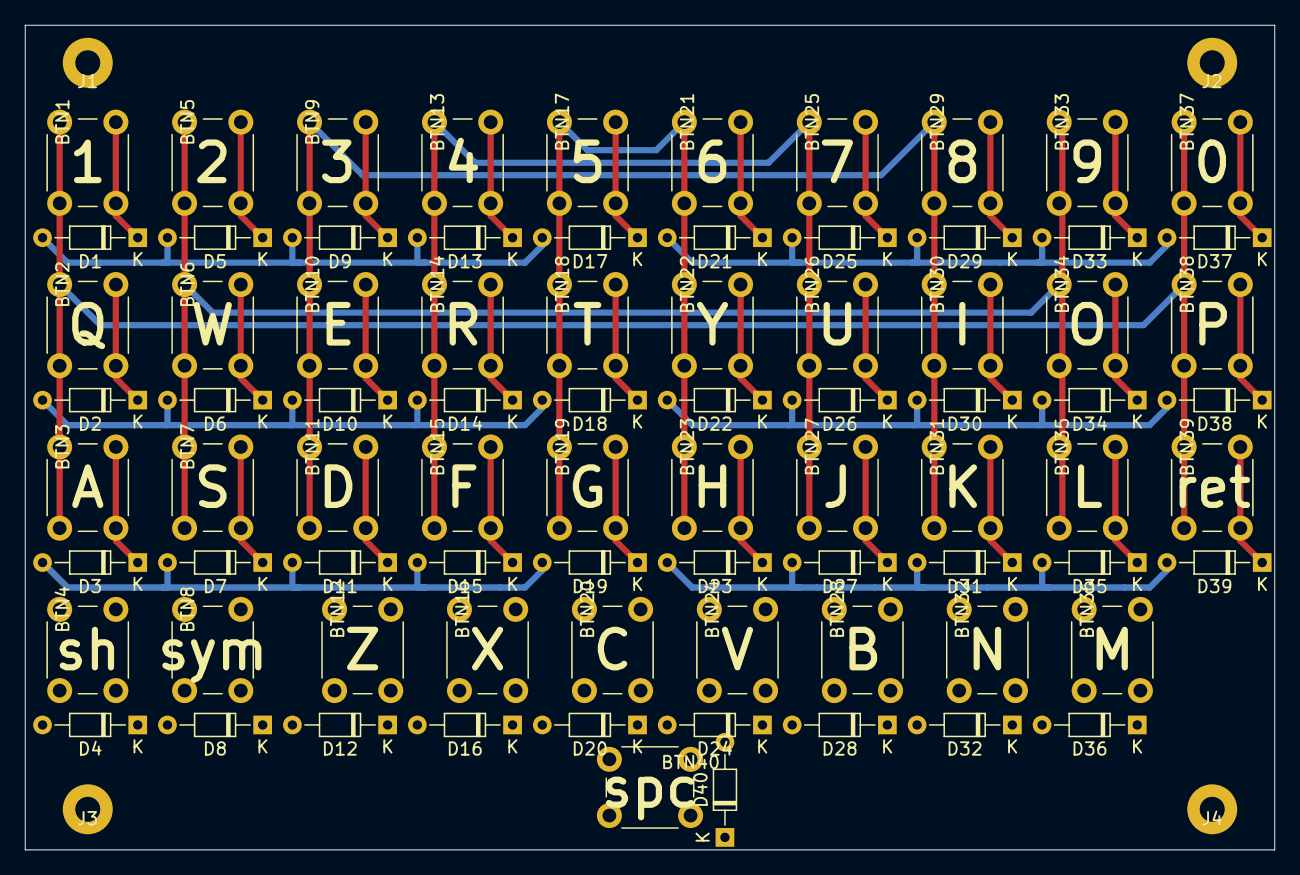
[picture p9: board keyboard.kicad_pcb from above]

Board: 2 copper layers, 100.0 x 66.0 mm, 84 parts (0 on the bottom side), 53 nets.

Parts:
BTN1: 1; SW_PUSH_6mm
BTN2: Q; SW_PUSH_6mm
BTN3: A; SW_PUSH_6mm
BTN4: SHIFT; SW_PUSH_6mm
BTN5: 2; SW_PUSH_6mm
BTN6: W; SW_PUSH_6mm
BTN7: S; SW_PUSH_6mm
BTN8: SYM; SW_PUSH_6mm
BTN9: 3; SW_PUSH_6mm
BTN10: E; SW_PUSH_6mm
BTN11: D; SW_PUSH_6mm
BTN12: Z; SW_PUSH_6mm
BTN13: 4; SW_PUSH_6mm
BTN14: R; SW_PUSH_6mm
BTN15: F; SW_PUSH_6mm
BTN16: X; SW_PUSH_6mm
BTN17: 5; SW_PUSH_6mm
BTN18: T; SW_PUSH_6mm
BTN19: G; SW_PUSH_6mm
BTN20: C; SW_PUSH_6mm
BTN21: 6; SW_PUSH_6mm
BTN22: Y; SW_PUSH_6mm
BTN23: H; SW_PUSH_6mm
BTN24: V; SW_PUSH_6mm
BTN25: 7; SW_PUSH_6mm
BTN26: U; SW_PUSH_6mm
BTN27: J; SW_PUSH_6mm
BTN28: B; SW_PUSH_6mm
BTN29: 8; SW_PUSH_6mm
BTN30: I; SW_PUSH_6mm
BTN31: K; SW_PUSH_6mm
BTN32: N; SW_PUSH_6mm
BTN33: 9; SW_PUSH_6mm
BTN34: o; SW_PUSH_6mm
BTN35: L; SW_PUSH_6mm
BTN36: btn; SW_PUSH_6mm
BTN37: 0; SW_PUSH_6mm
BTN38: P; SW_PUSH_6mm
BTN39: RET; SW_PUSH_6mm
BTN40: SPC; SW_PUSH_6mm
D1, D2, D3, D4, D5, D6, D7, D8, D9, D10, D11, D12, D13, D14, D15, D16, D17, D18, D19, D20, D21, D22, D23, D24, D25, D26, D27, D28, D29, D30, D31, D32, D33, D34, D35, D36, D37, D38, D39, D40: DIODE; D_DO-34_SOD68_P7.62mm_Horizontal
J1, J2, J3, J4: PIN; HOLE_2mm_Keep4mm

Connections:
/1: BTN1.2, D1.K
/2: BTN5.2, D5.K
/COL1: D1.A, D5.A, D9.A, D13.A, D17.A
/COL2: D2.A, D6.A, D10.A, D14.A, D18.A
/COL3: D3.A, D7.A, D11.A, D15.A, D19.A
/COL4: D4.A, D8.A, D12.A, D16.A, D20.A
/COL5: D21.A, D25.A, D29.A, D33.A, D37.A
/COL6: D22.A, D26.A, D30.A, D34.A, D38.A
/COL7: D23.A, D27.A, D31.A, D35.A, D39.A
/COL8: D24.A, D28.A, D32.A, D36.A, D40.A
/Q: BTN2.2, D2.K
/ROW1: BTN1.1, BTN2.1, BTN3.1, BTN4.1, BTN37.1, BTN38.1, BTN39.1, BTN40.1
/ROW2: BTN5.1, BTN6.1, BTN7.1, BTN8.1, BTN33.1, BTN34.1, BTN35.1, BTN36.1
/ROW3: BTN9.1, BTN10.1, BTN11.1, BTN12.1, BTN29.1, BTN30.1, BTN31.1, BTN32.1
/ROW4: BTN13.1, BTN14.1, BTN15.1, BTN16.1, BTN25.1, BTN26.1, BTN27.1, BTN28.1
/ROW5: BTN17.1, BTN18.1, BTN19.1, BTN20.1, BTN21.1, BTN22.1, BTN23.1, BTN24.1
/W: BTN6.2, D6.K
unnamed: BTN3.2, D3.K
unnamed: BTN4.2, D4.K
unnamed: BTN7.2, D7.K
unnamed: BTN8.2, D8.K
unnamed: BTN9.2, D9.K
unnamed: BTN10.2, D10.K
unnamed: BTN11.2, D11.K
unnamed: BTN12.2, D12.K
unnamed: BTN13.2, D13.K
unnamed: BTN14.2, D14.K
unnamed: BTN15.2, D15.K
unnamed: BTN16.2, D16.K
unnamed: BTN17.2, D17.K
unnamed: BTN18.2, D18.K
unnamed: BTN19.2, D19.K
unnamed: BTN20.2, D20.K
unnamed: BTN21.2, D21.K
unnamed: BTN22.2, D22.K
unnamed: BTN23.2, D23.K
unnamed: BTN24.2, D24.K
unnamed: BTN25.2, D25.K
unnamed: BTN26.2, D26.K
unnamed: BTN27.2, D27.K
unnamed: BTN28.2, D28.K
unnamed: BTN29.2, D29.K
unnamed: BTN30.2, D30.K
unnamed: BTN31.2, D31.K
unnamed: BTN32.2, D32.K
unnamed: BTN33.2, D33.K
unnamed: BTN34.2, D34.K
unnamed: BTN35.2, D35.K
unnamed: BTN36.2, D36.K
unnamed: BTN37.2, D37.K
unnamed: BTN38.2, D38.K
unnamed: BTN39.2, D39.K
unnamed: BTN40.2, D40.K

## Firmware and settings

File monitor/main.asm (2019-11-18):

	.include "system.inc"
	.include "ioport.inc"

	.text

	.extern	sci_init
	.extern sci_putchar
	.extern	sci_puts

	.global	_start
_start:
	lds	#0x7FFF

	/* Map registers and internal RAM to 0000h
	 * By default regs are mapped at 1000h
	 * This ONLY works if the monitor starts at boot, else this must be done
	 * by the bootstrap loader in special mode.
	 */
	clra
	staa	INIT+0x1000

	/* Now registers are at zero and we can use direct mode */

	bset	*PORTA #0x80 /* LED OFF */

	bsr	sci_init

	ldx	#motd
	jsr	sci_puts

	bra .

ledon:
	
	rts

	.section .rodata
motd:	.asciz	"sys11 monitor by f4grx v0.1\r\n"

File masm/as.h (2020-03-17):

/*
 *      machine independent definitions and global variables
 */

#define YES     1
#define NO      0
#define ERR     (-1)

#define MAXBUF  128
#define MAXOP   10      /* longest mnemonic */
#define MAXLAB  16
#define E_LIMIT 16
#define P_LIMIT 64

/*      Character Constants     */
#define NEWLINE '\n'
#define TAB     '\t'
#define BLANK   ' '
#define EOS     '\0'

/*      Opcode Classes          */
#define INH     0       /* Inherent                     */
#define GEN     1       /* General Addressing           */
#define IMM     2       /* Immediate only               */
#define REL     3       /* Short Relative               */
#define P2REL   4       /* Long Relative                */
#define P1REL   5       /* Long Relative (LBRA and LBSR)*/
#define NOIMM   6       /* General except for Immediate */
#define P2GEN   7       /* Page 2 General               */
#define P3GEN   8       /* Page 3 General               */
#define RTOR    9       /* Register To Register         */
#define INDEXED 10      /* Indexed only                 */
#define RLIST   11      /* Register List                */
#define P2NOIMM 12      /* Page 2 No Immediate          */
#define P2INH   13      /* Page 2 Inherent              */
#define P3INH   14      /* Page 3 Inherent              */
#define GRP2    15      /* Group 2 (Read/Modify/Write)  */
#define LONGIMM 16      /* Immediate mode takes 2 bytes */
#define BTB     17      /* Bit test and branch          */
#define SETCLR  18      /* Bit set or clear             */
#define CPD     19      /* compare d               6811 */
#define XLIMM   20      /* LONGIMM for X           6811 */
#define XNOIMM  21      /* NOIMM for X             6811 */
#define YLIMM   22      /* LONGIMM for Y           6811 */
#define YNOIMM  23      /* NOIMM for Y             6811 */
#define FAKE    24      /* convenience mnemonics   6804 */
#define APOST   25      /* A accum after opcode    6804 */
#define BPM     26      /* branch reg plus/minus   6804 */
#define CLRX    27      /* mvi x,0                 6804 */
#define CLRY    28      /* mvi y,0                 6804 */
#define LDX     29      /* mvi x,expr              6804 */
#define LDY     30      /* mvi y,expr              6804 */
#define MVI     31      /* mvi                     6804 */
#define EXT     32      /* extended                6804 */
#define BIT     33      /* bit manipulation        6301 */
#define SYS     34      /* syscalls (really swi)        */
#define PSEUDO  35      /* Pseudo ops                   */

/* global variables */
int     Line_num =0;            /* current line number          */
int     Err_count =0;           /* total number of errors       */
char    Line[MAXBUF] = {0};     /* input line buffer            */
char    Label[MAXLAB] = {0};    /* label on current line        */
char    Op[MAXOP] = {0};        /* opcode mnemonic on current line      */
char    Operand[MAXBUF] = {0};  /* remainder of line after op           */
char    *Optr =0;               /* pointer into current Operand field   */
int     Result =0;              /* result of expression evaluation      */
int     Force_word =0;          /* Result should be a word when set     */
int     Force_byte =0;          /* Result should be a byte when set     */
int     Pc =0;                  /* Program Counter              */
int     Old_pc =0;              /* Program Counter at beginning */

int     Last_sym =0;            /* result of last lookup        */

int     Pass =0;                /* Current pass #               */
int     N_files =0;             /* Number of files to assemble  */
FILE    *Fd =0;                 /* Current input file structure */
int     Cfn =0;                 /* Current file number 1...n    */
int     Ffn =0;                 /* forward ref file #           */
int     F_ref =0;               /* next line with forward ref   */
char    **Argv =0;              /* pointer to file names        */

int     E_total =0;             /* total # bytes for one line   */
int     E_bytes[E_LIMIT] = {0}; /* Emitted held bytes           */
int     E_pc =0;                /* Pc at beginning of collection*/

int     P_force = 0;            /* force listing line to include Old_pc */
int     P_total =0;             /* current number of bytes collected    */
int     P_bytes[P_LIMIT] = {0}; /* Bytes collected for listing  */

int     Cycles = 0;             /* # of cycles per instruction  */
long    Ctotal = 0;             /* # of cycles seen so far */
int     N_page = 0;             /* new page flag */
int     Page_num = 2;           /* page number */
int     CREflag = 0;            /* cross reference table flag */
int     Cflag = 0;              /* cycle count flag */
int     Lflag = 0;              /* listing flag 0=nolist, 1=list*/
int     Sflag = 0;              /* symbol table flag, 0=no symbol */
int     Debug = 0;              /* debug flag */
int     Binfil = 0;             /* binary image file output flag */
int     Hexfil = 0;             /* Intel Hex file output flag */
unsigned char Memmap[65536];	/* Memory image of output data */

struct link { /* linked list to hold line numbers */
       int L_num; /* line number */
       struct link *next; /* pointer to next node */
};

struct nlist { /* basic symbol table entry */
        char    *name;
        int     def;
        struct nlist *Lnext ; /* left node of the tree leaf */
        struct nlist *Rnext; /* right node of the tree leaf */ 
        struct link *L_list; /* pointer to linked list of line numbers */
};

struct oper {   /* an entry in the mnemonic table */
        char    *mnemonic;      /* its name */
        char    class;          /* its class */
        int     opcode;         /* its base opcode */
        char    cycles;         /* its base # of cycles */
};

struct  nlist *root;            /* root node of the tree */
  
FILE    *Objfil =0;             /* object file's file descriptor*/
char    Obj_name[] = {"             "};

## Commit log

2019-10-18 start uart code
2019-10-21 Split uart definitions in an include file add a text file describing memory map
2019-10-28 prepare new options reset and run
    [upload.py]
2019-10-29 avoid using exceptions catch serial port open error rts reset no more a todo item
    [upload.py]
2019-10-30 add a stage2 python tool and update gitignore
2019-11-03 upload.py: check for serial instead of crash, enable terminal mode stage2: setup LED on PA7 as life signal.
    [upload.py]
2019-11-06 More code to receive data frames
2019-11-06 More bits in stage2 uploader
2019-11-06 stage2: improve buffer handling
2019-11-06 stage2: enable extended mode
2019-11-07 add a skeleton for a ROM monitori rework parts of uploader
    [main.asm, upload.py]
2019-11-08 add readme for board
2019-11-12 console: display correct chars
    [upload.py]
2019-11-12 ram test OK on my board!
2019-11-16 actually init uart to allow boot without loader, remove noise in uploader
    [upload.py]
2019-11-20 add schematic and initial component placement for miniboard
    [hc11main.kicad_pcb, hc11main.sch, hc11main_protoboard.sch]
2019-11-20 uploader: search stage2.bin in another path
2019-11-20 add some pics of the prototype
2019-11-29 same address scheme in C, compute asm flags, we're close
    [hc11main.kicad_pcb, hc11main.sch]
2019-12-02 cut long lines, add core rw funcs, add getopt example from man page
2019-12-03 implemented RTS, uart init and puts are called and return!
2019-12-16 fixed addressing modes, add debug, map some ram that exists on the board, give names to mem zones
2019-12-18 simulate the SCI using a tcp socket connection, also add -w option to main to start without a binary (RAM is mapped in the monitor address space) and load monitor via gdb instead.
2019-12-23 add a doc to help design the assembler
2019-12-24 attempt to open stage2 in alternate location to avoid using a symlink
    [upload.py]
2020-01-01 add spi regs definitions
2020-01-06 add structure for spi bus driver
2020-01-09 more hardware around
    [hc11main.kicad_pcb, hc11main.sch, hc11main_protoboard.sch]
2020-01-10 add spi select/deselect prototypes
2020-01-10 add device manager
2020-01-10 make sure full cmdlist is available, fix inttostr, start enum devices
2020-01-13 add design for a keyboard
    [keyboard.kicad_pcb, keyboard.sch]
2020-01-15 Shell is now more modular. Functions could be reused. -shell_readline usable for ed text editor -shell_parse and shell_exec to interpret shell command files -shell_parse for assembler programs
2020-01-16 implement asl,asla,aslb,bge,blti, monitor now displays devices
2020-03-13 upload.py: select terminal baud rate monitor: disable blockdev stuff, configure uart at 9600 bauds monitor_apps: rename as11 to forth, assembler will be written in forth. TODO: replace whole shell wi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
    [upload.py]
2020-03-17 add an absolute hc11 assembler
2020-03-23 small fixes, execution starts, error when recursing into new wordlist
    [main.asm]
2020-03-25 save some bytes in branch, more comments about stack, fix stack handling
    [main.asm]
2020-03-26 fix dup that requires incrementing by 2 not 1
    [main.asm]
2020-04-16 fix linking, dic parser is now ok
    [forthdic.py, main.asm]
2020-04-17 fix sim pulls, now CR is working, TODO IMMSTR/COUNT/TYPE
    [main.asm]
2020-04-17 fix native stack ops, TYPE is close to working but not yet
    [main.asm]
2020-04-17 fix PLUS, then IMMSTR,COUNT,TYPE are working. We get a prompt.
    [main.asm]
2020-04-23 execute is a jump that will interrupt the current word and branch to a new one. so calling it directly from EVAL was stopping the interpretation of further words. EXECUTE has to be launched from a su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
2020-04-24 turn one last sim core printf into a log msg enable -d cmdline option
2020-04-27 fix word links current code is able to spit the word list, which means that parts of "FIND" are OK update python dic parser to match the new use of pascal strings for token names
    [forthdic.py, main.asm]
2020-04-28 improve str compare, no more stack error. csame stubbed, TODO
    [main.asm]
2020-04-29 fix parser to display words without header remove more debug words and cleanup prompt
    [forthdic.py, main.asm]
2020-05-01 progress but not ok yet Testing on real hc11 cpu is OK, so we have a simulator bug. maybe in the recently implemented ROT?
    [main.asm]
2020-05-02 add words for number output (seems broken) add instruction counter stats add initial code to allow core testing to find core bugs
    [main.asm]
2020-05-04 fix confusion between HOLD word and HOLDP address
    [main.asm]
2020-05-04 Support simulation interruption on core execution of STOP
2020-05-04 fix a fundamental flaw in EXECUTE that previously could only run forth words (not native ones) in a bad way by just jumping at the next word instead of running the code pointer of the word! Now numer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
    [main.asm]
2020-05-06 add SP@, use to debug. still not working.
    [main.asm]
2020-05-06 fix printf format
2020-05-06 INTERPRETER WORKS! remove lots of debug fix S@ name length
    [main.asm]
2020-05-07 implement VER and him prepare error mgmt
    [main.asm]
2020-05-07 implement THROW and manage parse errors
    [main.asm]
2020-05-08 rework IMMSTR to allow other words to be followed by string litterals, like abortz. implement STACK? to check underflow, it does not work because inner interpreter also need a stack bucket to jump to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
    [main.asm]
2020-05-12 implement KEY with KEY?, implement NUF? (seems broken), MIN, MAX, U.R, .R, SPACES, TCHAR, and some tools : _TYPE, dm+, DUMP, .S
    [main.asm]
2020-05-13 fix some word links
    [main.asm]
2020-05-13 avoid edges to return
    [forthdic.py]
2020-05-13 avoid edges to imm
    [forthdic.py]
2020-05-13 avoid edges to branch
    [forthdic.py]
2020-05-13 This compiler manages to assemble a word, but creates a bad header. TOFIX but good start.
2020-05-13 compiler builds correct colon definitions but ; do not link them in the dictionary yet. TODO semicolon has to update LASTP with the value of HERE when the compiler started.
    [main.asm]
2020-05-14 introduce SHOWSTR to replace IMMSTR...COUNT TYPE ABORTZ -> ABORTNZ Interpreter now detects compile-only words Fixed inline string compilation (scompq) Implement compile-time ABORT" ." and $" factoriz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
    [forthdic.py, main.asm]
2020-05-14 CREATE and VARIABLE are working. They are implemented with DOVAR that stacks the address right after dovar and returns execution to the word that colled the word that uses dovar (oof) I can see how t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
    [main.asm]
2020-05-15 Implenting DOES with some success. Testing with: : INH CREATE C, DOES> C@ C, ; ok 42 INH NOP ok $100 64 DUMP 100 F2 9C 3 49 4E 48 E0 2B EF FD ED D1 E1 57 1 1A r__INH`+o}mQaW__ 110 E1 57 0 54 E1 9B E1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
    [main.asm]
2020-05-16 fixed SNAME stack spill, now DOES> works ok. Also adjusted python tool to support does. Example geared towards assembler:
    sys11 forth ver 1.00
    : INH CREATE C, DOES> C@ C, ; ok \ Generic inherent asm word: Stores an opcode byte, which is reloaded then emitted to data space on demand.
    42 INH NOP ok \ Instanciate INH by creating word NOP, storing 42 in created data field.
    HERE . 303 ok \ current data pointer
    303 C@ . 2 ok \ contains an arbitrary byte
    NOP ok \ we call the NOP that was created by INH using DOES
    303 C@ . 42 ok\ now HERE points to the value we passed to NOP
    HERE . 304 ok \ and here was incremented, confirming the effect of DOES> code.
    [forthdic.py, main.asm]
2020-05-18 implement native 68HC11 multiplication to replace eForth UM*. Add simulator support for MUL. Carry behaviour on intermediate products to be tested. Sprinkle some more comments here and here.
    [main.asm]
2020-05-19 current status of F2012 compliance completed
2020-05-19 Replace behaviour vector by STATE, which is normalized to zero when interpreting and -1 when compiling.
    [main.asm]
2020-05-22 fix find to use word list traversal and repair namecompare.
    [main.asm]
2020-05-26 Validated hardware UM/MOD on several pathological cases. Used 5 more asm bytes. Examples that were previously failing: 57479 24148 56224 UM/MOD U. U. 28148 27655 ok 17320 1738 2868 UM/MOD U. U. 39720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
    [main.asm]
2020-06-10 main board: continue routing
    [hc11main.kicad_pcb, hc11main.sch]
2020-06-26 almost completed routing
    [hc11main.kicad_pcb, hc11main.sch]
2020-06-29 move main board to its own repo
    [hc11main.kicad_pcb, hc11main.sch, hc11main_protoboard.sch]
